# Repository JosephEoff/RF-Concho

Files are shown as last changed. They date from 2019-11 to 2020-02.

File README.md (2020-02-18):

# RF-Concho
[A hat band for a nerd.](https://josepheoff.github.io/posts/1-hatband)

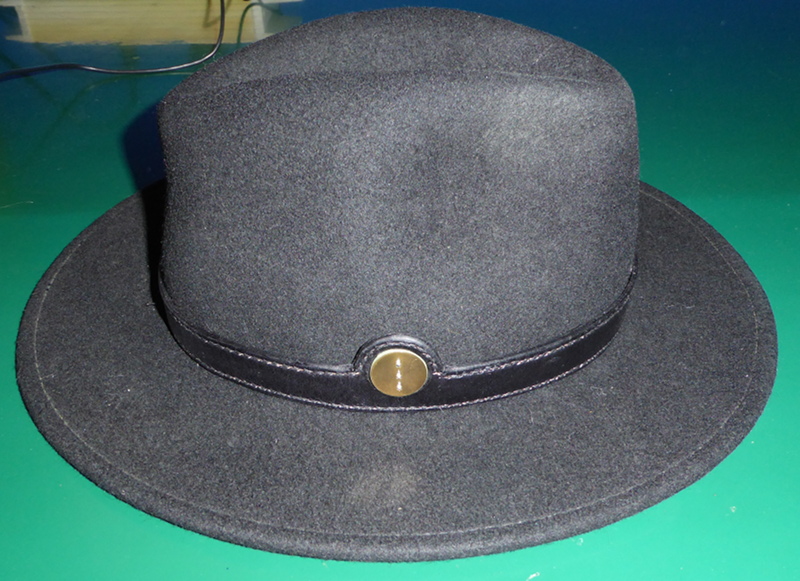
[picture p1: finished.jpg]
Finished hatband


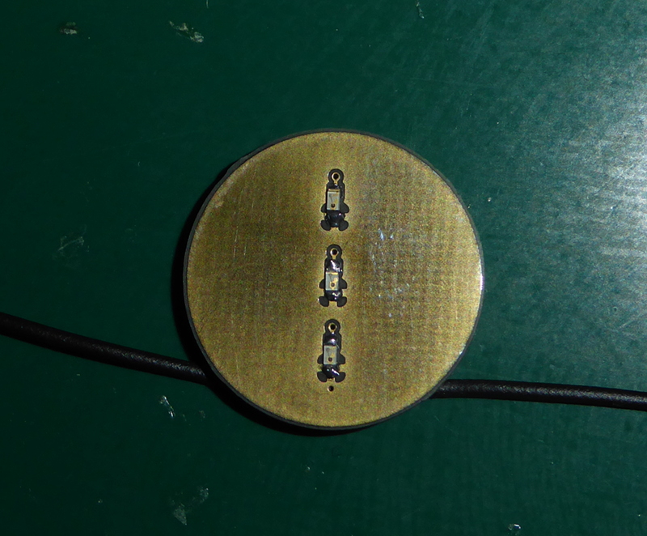
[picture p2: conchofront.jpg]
Concho front


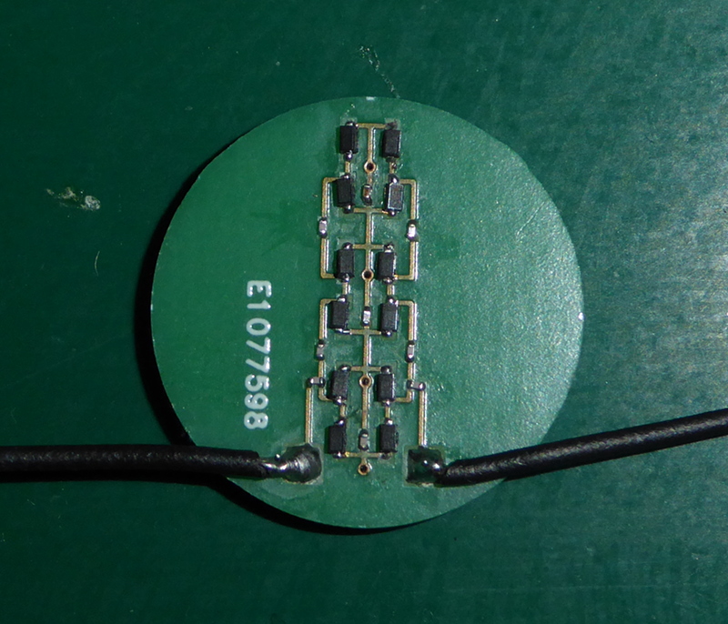
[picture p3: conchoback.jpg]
Concho back


This project contains all the circuit diagrams and drawings needed to make a hat band with a passive cell phone detector.

The "range" is a  few centimeters at most - it isn't intended for any kind of serious measurement.

I made it because I could, and because the hat band on my fedora snapped.

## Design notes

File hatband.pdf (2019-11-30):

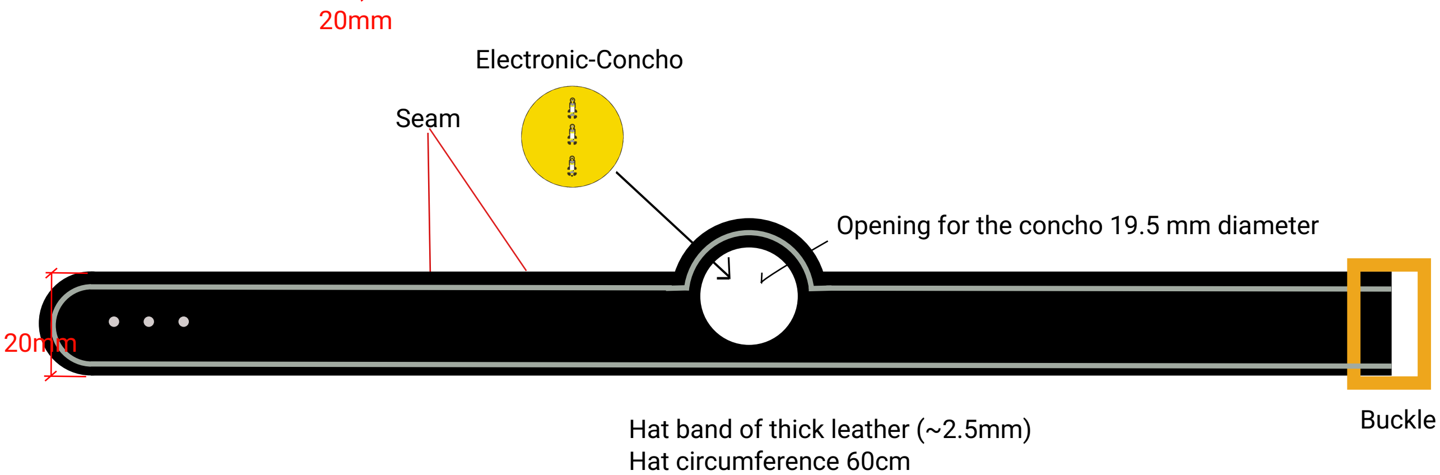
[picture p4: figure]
Hat band of thick leather (~2.5mm) Hat circumference 60cm; Seam; Electronic-Concho; Buckle; Opening for the concho 19.5 mm diameter

Band 60 cm plus extra for the buckle and the buckle holes Black leather with black thread
Use smooth leather

Back of thin leather (1 bis 1.5mm) Sew behind the opening in the band 10cm long

Do not sew the ends.

Concho and buckle should be on opposite sides of the hat when worn.

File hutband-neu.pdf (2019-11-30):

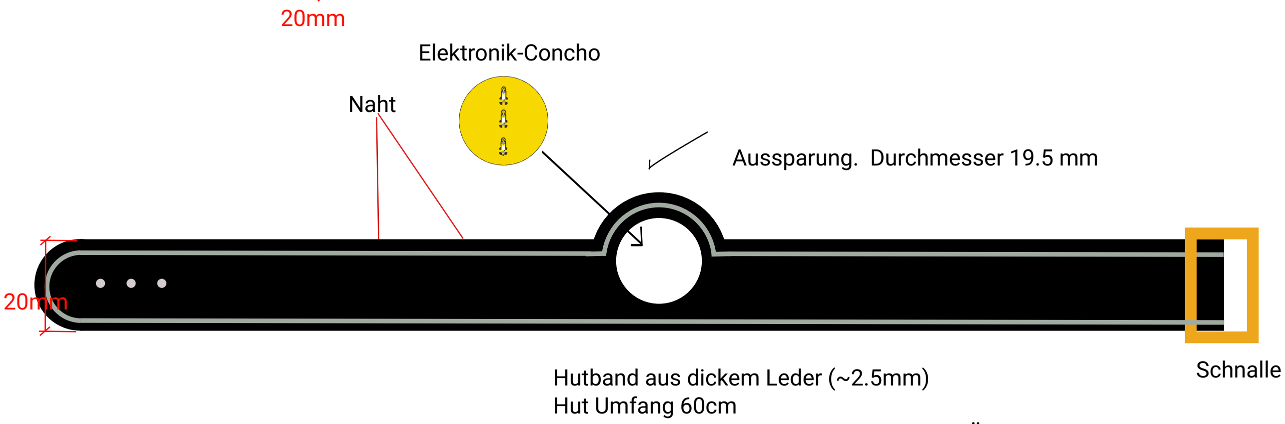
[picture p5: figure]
Hutband aus dickem Leder (~2.5mm) Hut Umfang 60cm; Naht; Elektronik-Concho; Schnalle; Aussparung. Durchmesser 19.5 mm

Band 60 cm plus Zusatz für Schnalle und Überhang Schwarze Leder mit schwarze Garn genäht Glattes Leder benutzen

Rückenwand aus dünnem Leder (1 bis 1.5mm) Wird hinter die Aussparung genäht
10cm länge

An den Enden nicht zunähen.
Die Antenna-Drähte müssen da durch.

Concho und Schnalle sollten sich gegenüber befinden

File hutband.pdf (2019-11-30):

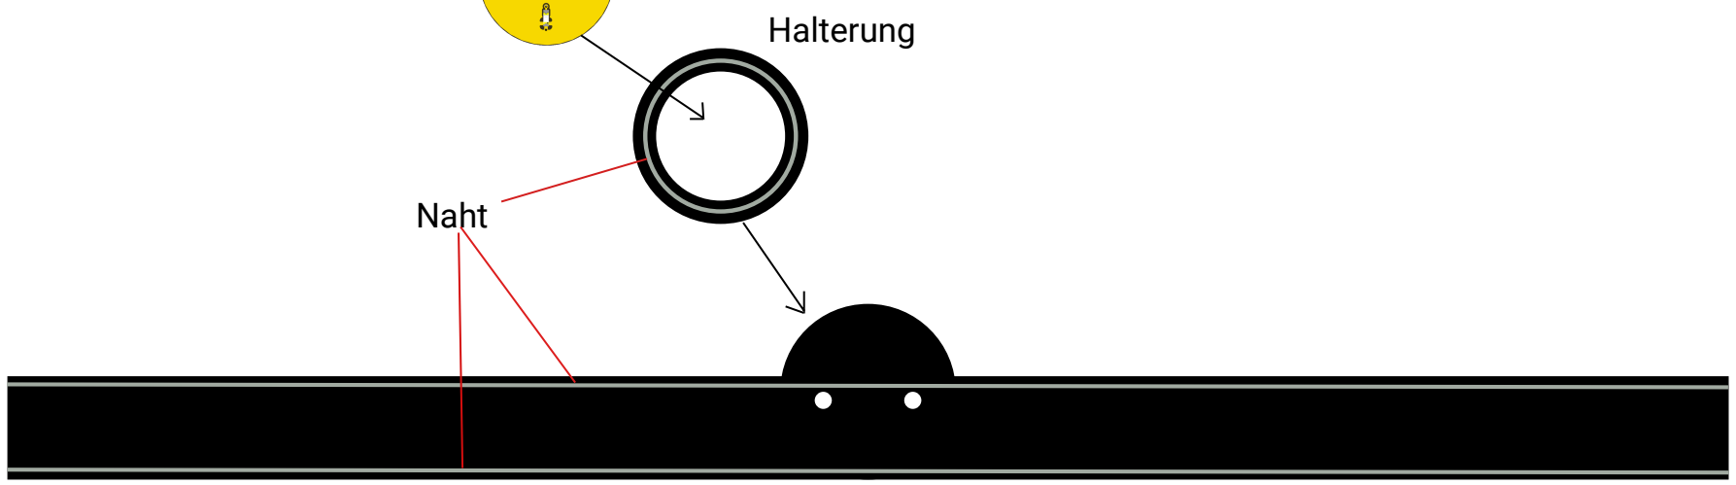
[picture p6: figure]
Halterung; Naht

Hutband.
Hut Umfang 60cm
Band 60 cm plus Zusatz für Schnalle und Überhang

Elektronik-Concho

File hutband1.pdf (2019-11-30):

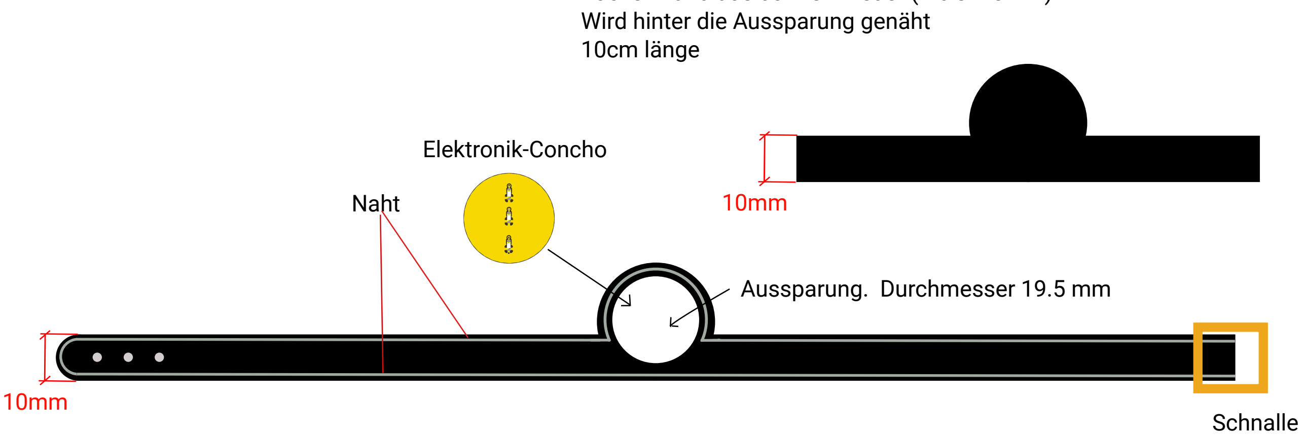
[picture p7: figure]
Naht; Elektronik-Concho; Wird hinter die Aussparung genäht 10cm länge; Schnalle; Aussparung. Durchmesser 19.5 mm

Hutband aus dickem Leder (~2.5mm)
Hut Umfang 60cm
Band 60 cm plus Zusatz für Schnalle und Überhang Schwarze Leder mit schwarze Garn genäht Glattes Leder benutzen

Rückenwand aus dünnem Leder (1 bis 1.5mm)

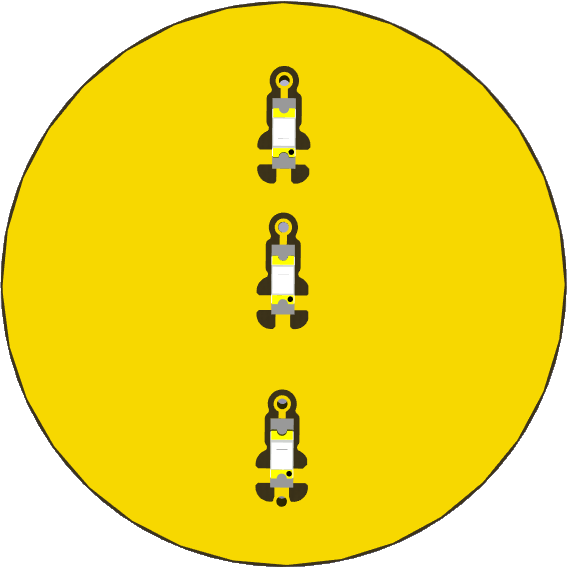
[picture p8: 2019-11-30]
Concho.png

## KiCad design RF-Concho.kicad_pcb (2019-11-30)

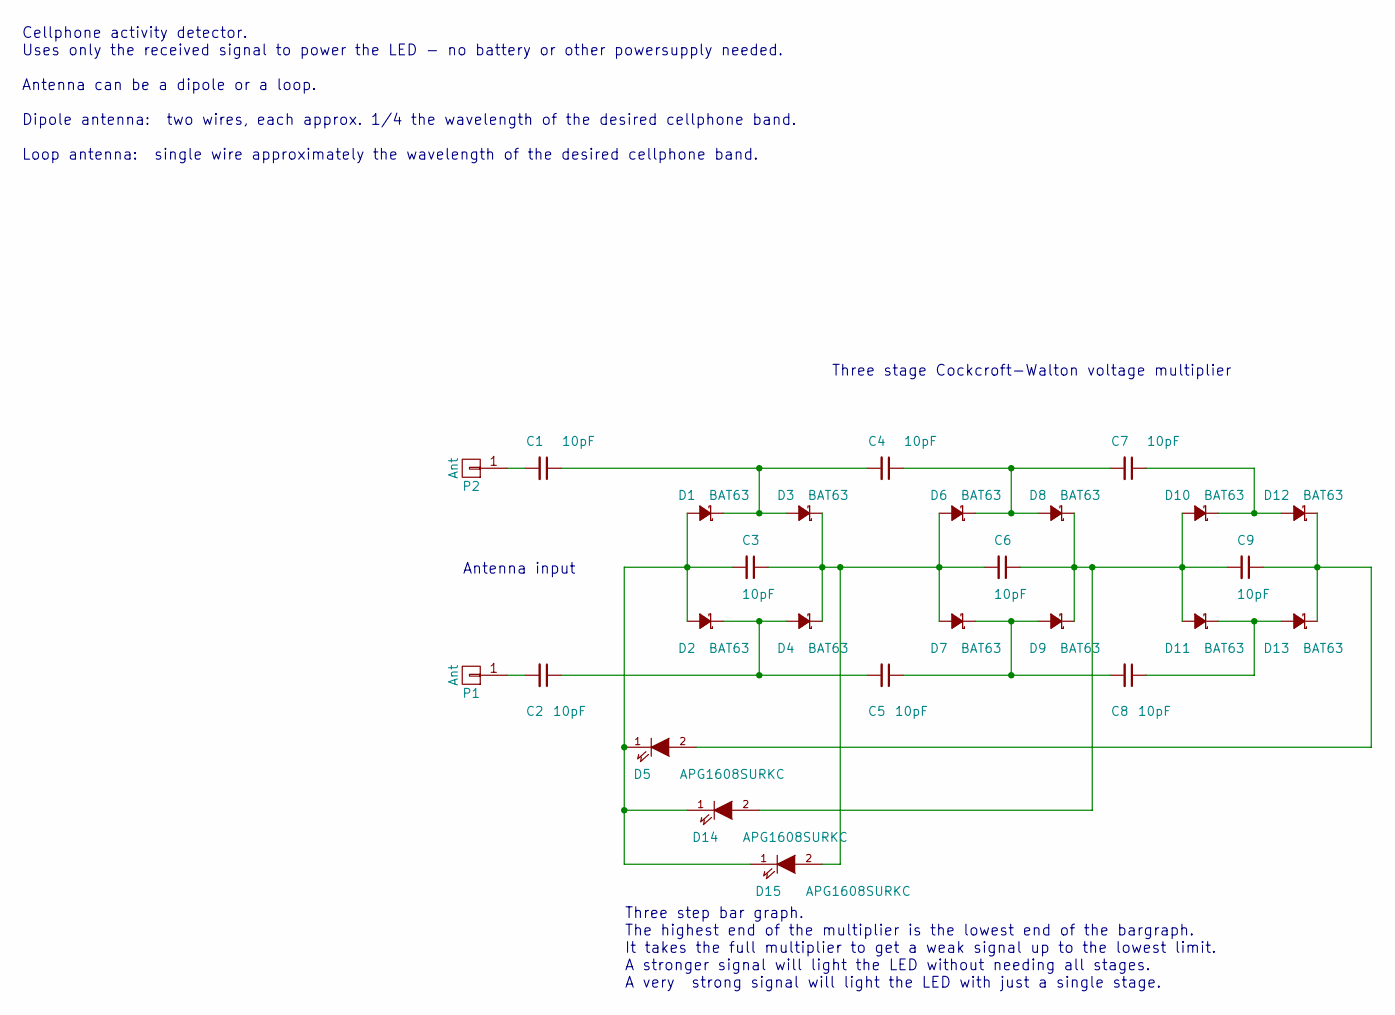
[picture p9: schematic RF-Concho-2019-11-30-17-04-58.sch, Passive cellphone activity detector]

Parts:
C1, C2, C3, C4, C5, C6, C7, C8, C9: 10pF; C_0201
D1, D2, D3, D4, D6, D7, D8, D9, D10, D11, D12, D13: BAT63; D_SC-79
D5, D14, D15: APG1608SURKC; LED_0603
P1, P2: Ant; Measurement_Point_Square-SMD-Pad_Small

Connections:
unnamed: C1.1, C4.2, D1.1 (K), D3.2 (A)
unnamed: C1.2, P2.1
unnamed: C2.1, C5.2, D2.1 (K), D4.2 (A)
unnamed: C2.2, P1.1
unnamed: C3.1, C6.2, D3.1 (K), D4.1 (K), D6.2 (A), D7.2 (A), D15.2 (A)
unnamed: C3.2, D1.2 (A), D2.2 (A), D5.1 (K), D14.1 (K), D15.1 (K)
unnamed: C4.1, C7.2, D6.1 (K), D8.2 (A)
unnamed: C5.1, C8.2, D7.1 (K), D9.2 (A)
unnamed: C6.1, C9.2, D8.1 (K), D9.1 (K), D10.2 (A), D11.2 (A), D14.2 (A)
unnamed: C7.1, D10.1 (K), D12.2 (A)
unnamed: C8.1, D11.1 (K), D13.2 (A)
unnamed: C9.1, D5.2 (A), D12.1 (K), D13.1 (K)

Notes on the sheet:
Three stage Cockcroft-Walton voltage multiplier
Antenna input
Cellphone activity detector. Uses only the received signal to power the LED - no battery or other powersupply needed. Antenna can be a dipole or a loop. Dipole antenna: two wires, each approx. 1/4 the wavelength of the desired cellphone band. Loop antenna: single wire approximately the wavelength o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
Three step bar graph. The highest end of the multiplier is the lowest end of the bargraph. It takes the full multiplier to get a weak signal up to the lowest limit. A stronger signal will light the LED without needing all stages. A very strong signal will light the LED with just a single stage.

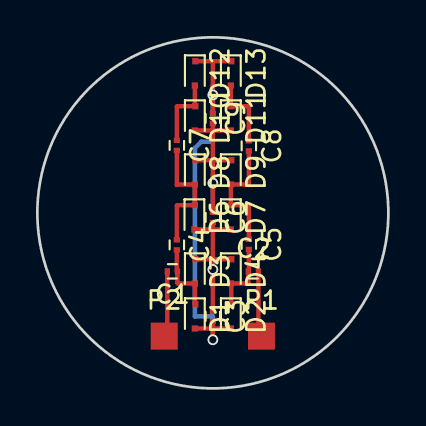
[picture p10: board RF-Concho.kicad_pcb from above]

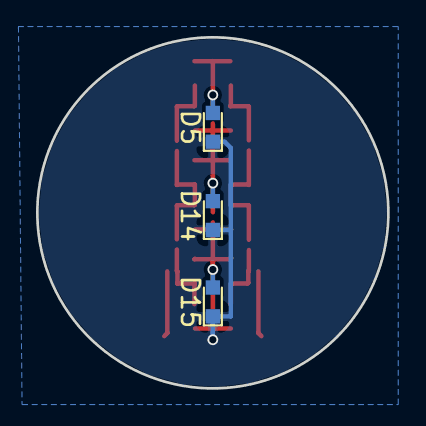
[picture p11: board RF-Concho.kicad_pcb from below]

Board: 2 copper layers, 19.5 x 19.5 mm, 26 parts (3 on the bottom side), 12 nets.

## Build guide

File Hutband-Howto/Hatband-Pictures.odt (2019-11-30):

Leather pieces – front side (smooth leather)

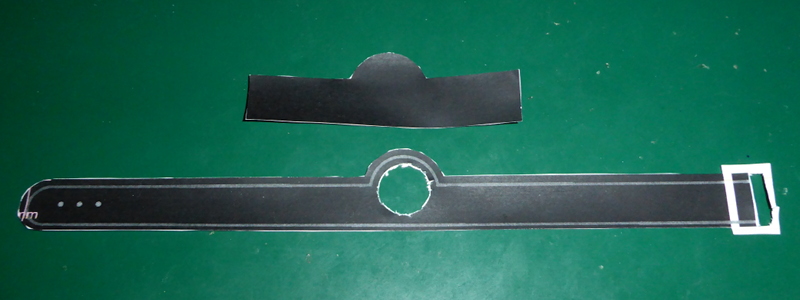
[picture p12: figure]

Leather pieces – back side (rough leather)

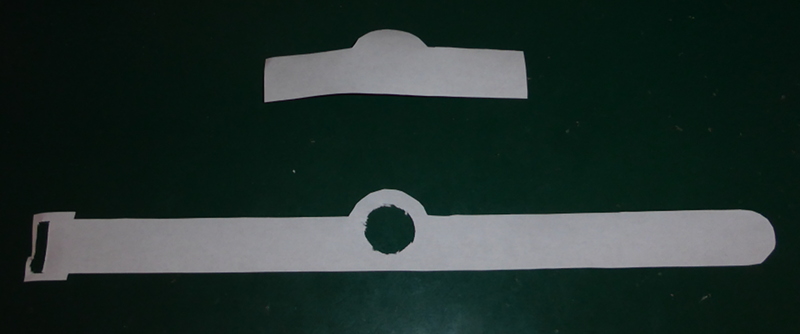
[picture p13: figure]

Both parts together:

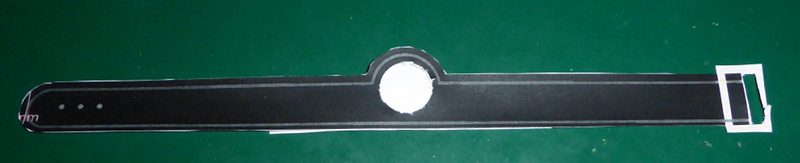
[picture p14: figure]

The gray lines are the seams. Sew only along the marked lines.

Finished hatband from behind:

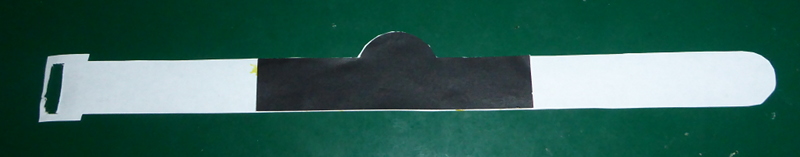
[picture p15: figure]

Finished hatband with antenna wire from the front side:

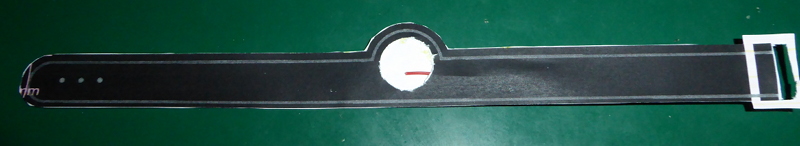
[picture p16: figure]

Finished hatband with antenna wire (red) from the back.

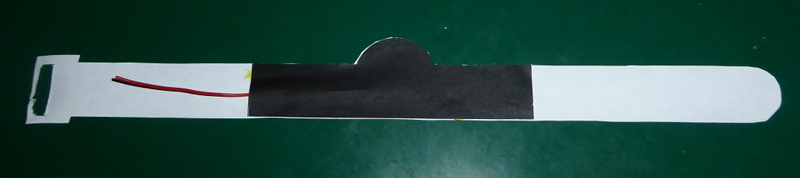
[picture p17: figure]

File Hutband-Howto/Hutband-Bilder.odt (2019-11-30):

Lederteile – Vorderseite (glatte Leder)


Lederteile – Rückseite (rauhes Leder)


Beide Teile zusammengelegt:


Die graue Linien stellen die Nähte dar. Nur an die graue Linien zusammen nähen

Fertige Band von hinten:


Fertige Band mit Antennen-Draht (rot) von vorne


Fertige Band mit Antennen-Draht (rot) von hinten.


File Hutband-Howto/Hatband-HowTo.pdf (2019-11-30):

Leather pieces – front side (smooth leather)

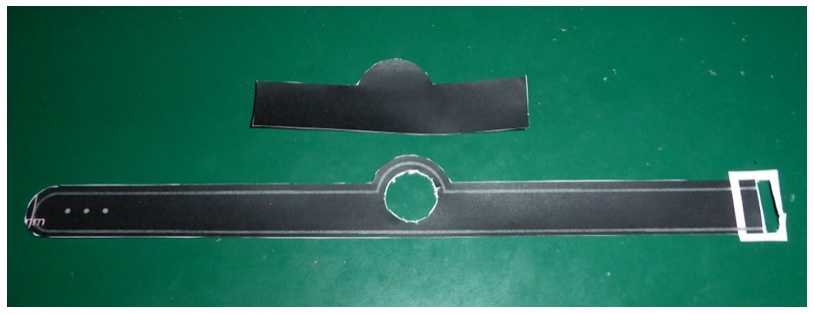
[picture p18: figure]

Leather pieces – back side (rough leather)

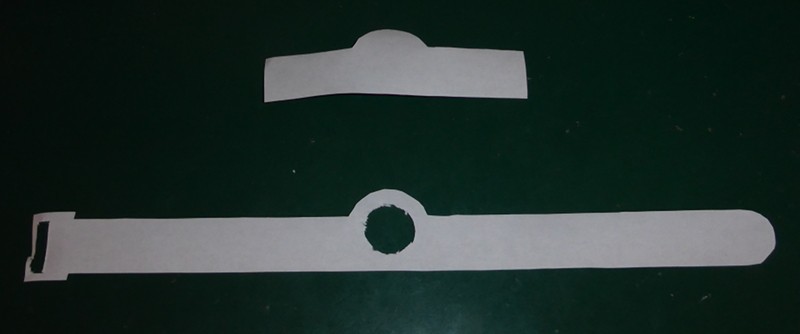
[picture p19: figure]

Both parts together:

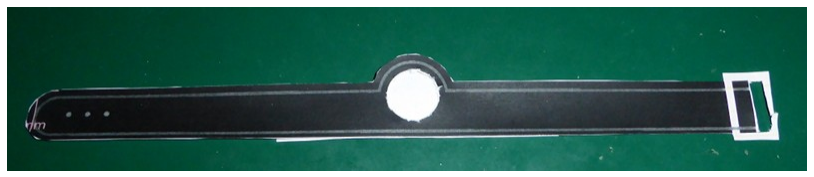
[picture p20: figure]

The gray lines are the seams. Sew only along the marked lines.

Finished hatband from behind:

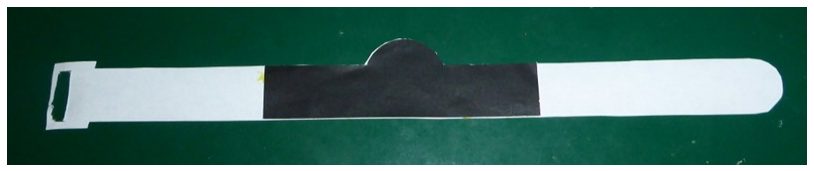
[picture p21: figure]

Finished hatband with antenna wire from the front side:

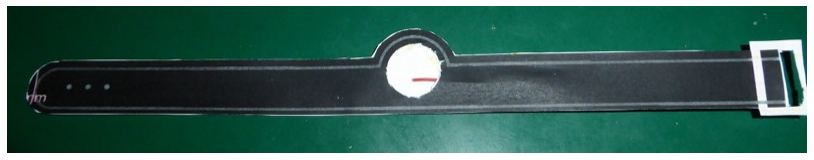
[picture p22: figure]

Finished hatband with antenna wire (red) from the back.

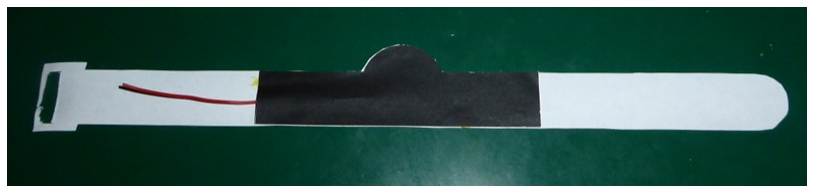
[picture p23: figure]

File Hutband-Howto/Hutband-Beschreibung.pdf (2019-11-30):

Lederteile – Vorderseite (glatte Leder)


Lederteile – Rückseite (rauhes Leder)


Beide Teile zusammengelegt:


Die graue Linien stellen die Nähte dar. Nur an die graue Linien zusammen nähen

Fertige Band von hinten:


Fertige Band mit Antennen-Draht (rot) von vorne


Fertige Band mit Antennen-Draht (rot) von hinten.


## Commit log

2019-11-30 Created repository
    [RF-Concho.kicad_pcb, RF-Concho.sch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]
2019-11-30 Update to KiCad 5
    [RF-Concho-2019-11-30-17-04-58.sch]
